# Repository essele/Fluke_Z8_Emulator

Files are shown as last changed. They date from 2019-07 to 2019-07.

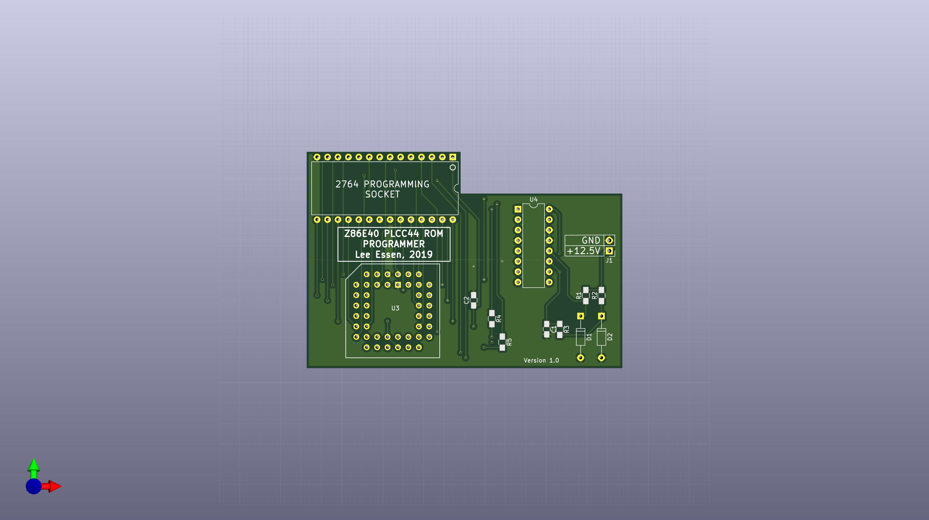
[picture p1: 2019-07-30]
pcb/8840A_CPU_Programmer/8840A_CPU_Programmer.jpg

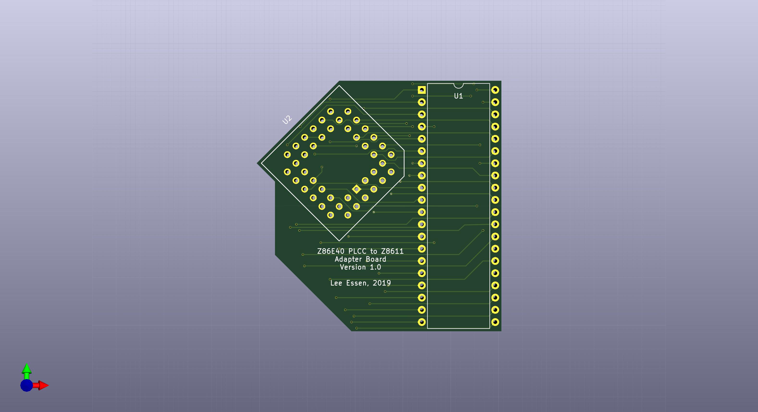
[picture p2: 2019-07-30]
pcb/8840A_CPU.jpg

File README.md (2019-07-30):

# Fluke_Z8_Emulator

This is a attempt at a Z8 emulator using a PSoC processor that can be used in a Fluke 8840A multimeter, and possibly a Fluke 8842A multimeter (although I have not tested the latter.)

I'm releasing this in the hope that someone will be able to help fix the remaining issue, the code is currently in a messy state as I've not had a chance to clean it up prior to releasing it.

The pcb and schematic (KiCad format) are available in the pcb directory.

The PSoC Creator workspace is in the PSoC_Workspace directory.

** THIS IS FAR FROM PRODUCTION WORTHY **

Some known issues:

1. There is a mistake on the PCB where all the P5 pins are offset by one, this doesn't cause a problem as it can be fixed by configuration, I'll fix this on the next version.

2. The GPIB board doesn't work properly. It works ok with external trigger set, but you get intermittent strange behaviour if not using the external trigger (more info below.)

3. I'm not entirely sure everything else is ok as I've hacked around with just about everything trying to fix the GPIB problem.

I'm fairly sure the outstanding issue is one of three things:

- A mis-implemented instruction
- Still something wrong with interrupts and masking
- A timing thing

Basic Description:

** I will spend some time documenting this properly, but for now here is a very brief overview **

Port 0 and 1 -- there is a verilog module that recreates the Z8 bus protocol which controls most of port 0 and 1.

Port 2 -- port 2 is a completely normal port, handled by firmware.

Port 3 -- port 3 is made up of incoming interrupts, one input sense line, and serial and timer.

Timer 1 -- the timer is implemented using a PSoC timer, but with a verilog module attached to the output to toggle the output at the end of each timing cycle. There is also the ability to set the output to 1 to copy the behaviour of the Z8 timer.

Serial -- currently there are three different serial implementations (all attempting to fix the GPIB problem), however the behaviour is the same with all of them, so I don't think it's related. The standard PSoC UART module is used for tx, I then have two verilog RX modules. SerialDRX is implemented using a datapath component so is lightweight and needs to be used if the timer block is also used. (I'm quite pleased with this as it's super efficient as it uses the datapath for both timer and shift register!)

TODO's for the next version...

1. Redo the whole bus access bit ... there are probably quite a lot of efficiencies to be had to give us more headroom for other things.

2. New board ... different output for the clock signal. Re-look at the P3 pins ... why did they stick the debug pins in the middle of a useful port???

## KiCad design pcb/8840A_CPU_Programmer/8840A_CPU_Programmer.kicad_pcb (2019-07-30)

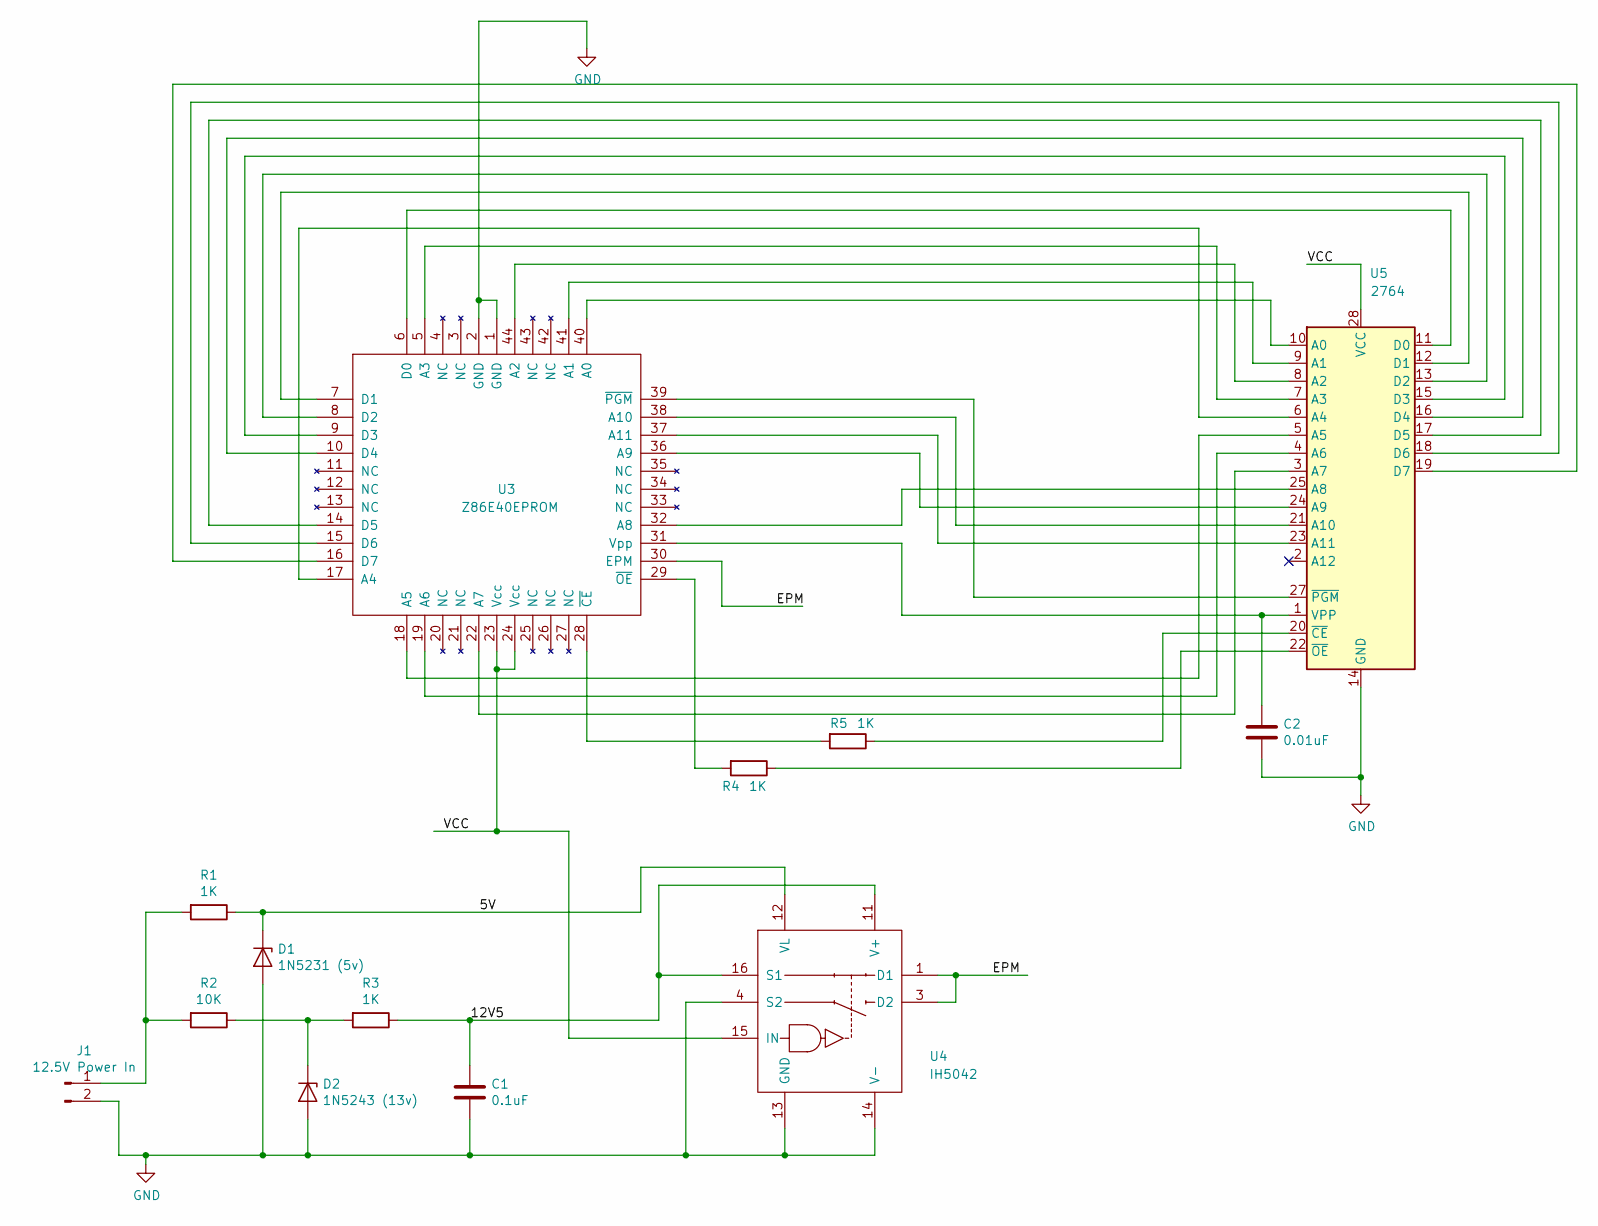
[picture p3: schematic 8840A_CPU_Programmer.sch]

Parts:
C1: 0.1uF; C_0805_HandSoldering
C2: 0.01uF; C_0805_HandSoldering
D1: 1N5231 (5v); D_DO-35_SOD27_P10.16mm_Horizontal
D2: 1N5243 (13v); D_DO-35_SOD27_P10.16mm_Horizontal
J1: 12.5V Power In; Pin_Header_Straight_1x02_Pitch2.54mm
R1, R3, R4, R5: 1K; R_0805_HandSoldering
R2: 10K; R_0805_HandSoldering
U3: Z86E40EPROM; PLCC44
U4: IH5042; DIP-16_W7.62mm
U5: 2764; DIP-28_W15.24mm

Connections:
/5V: D1.1 (K), R1.1, U4.12 (VL)
/12V5: C1.1, R3.1, U4.11 (V+), U4.16 (S1)
/EPM: U3.30 (EPM), U4.1 (D1), U4.3 (D2)
/VCC: U3.23 (Vcc), U3.24 (Vcc), U4.15 (IN), U5.28 (VCC)
GND: C1.2, C2.2, D1.2 (A), D2.2 (A), J1.2, U3.1 (GND), U3.2 (GND), U4.4 (S2), U4.13 (GND), U4.14 (V-), U5.14 (GND)
unnamed: C2.1, U3.31 (Vpp), U5.1 (VPP)
unnamed: D2.1 (K), R2.1, R3.2
unnamed: J1.1, R1.2, R2.2
unnamed: R4.1, U5.22 (~OE)
unnamed: R4.2, U3.29 (~OE)
unnamed: R5.1, U5.20 (~CE)
unnamed: R5.2, U3.28 (~CE)
unnamed: U3.5 (A3), U5.7 (A3)
unnamed: U3.6 (D0), U5.11 (D0)
unnamed: U3.7 (D1), U5.12 (D1)
unnamed: U3.8 (D2), U5.13 (D2)
unnamed: U3.9 (D3), U5.15 (D3)
unnamed: U3.10 (D4), U5.16 (D4)
unnamed: U3.14 (D5), U5.17 (D5)
unnamed: U3.15 (D6), U5.18 (D6)
unnamed: U3.16 (D7), U5.19 (D7)
unnamed: U3.17 (A4), U5.6 (A4)
unnamed: U3.18 (A5), U5.5 (A5)
unnamed: U3.19 (A6), U5.4 (A6)
unnamed: U3.22 (A7), U5.3 (A7)
unnamed: U3.32 (A8), U5.25 (A8)
unnamed: U3.36 (A9), U5.24 (A9)
unnamed: U3.37 (A11), U5.23 (A11)
unnamed: U3.38 (A10), U5.21 (A10)
unnamed: U3.39 (~PGM), U5.27 (~PGM)
unnamed: U3.40 (A0), U5.10 (A0)
unnamed: U3.41 (A1), U5.9 (A1)
unnamed: U3.44 (A2), U5.8 (A2)

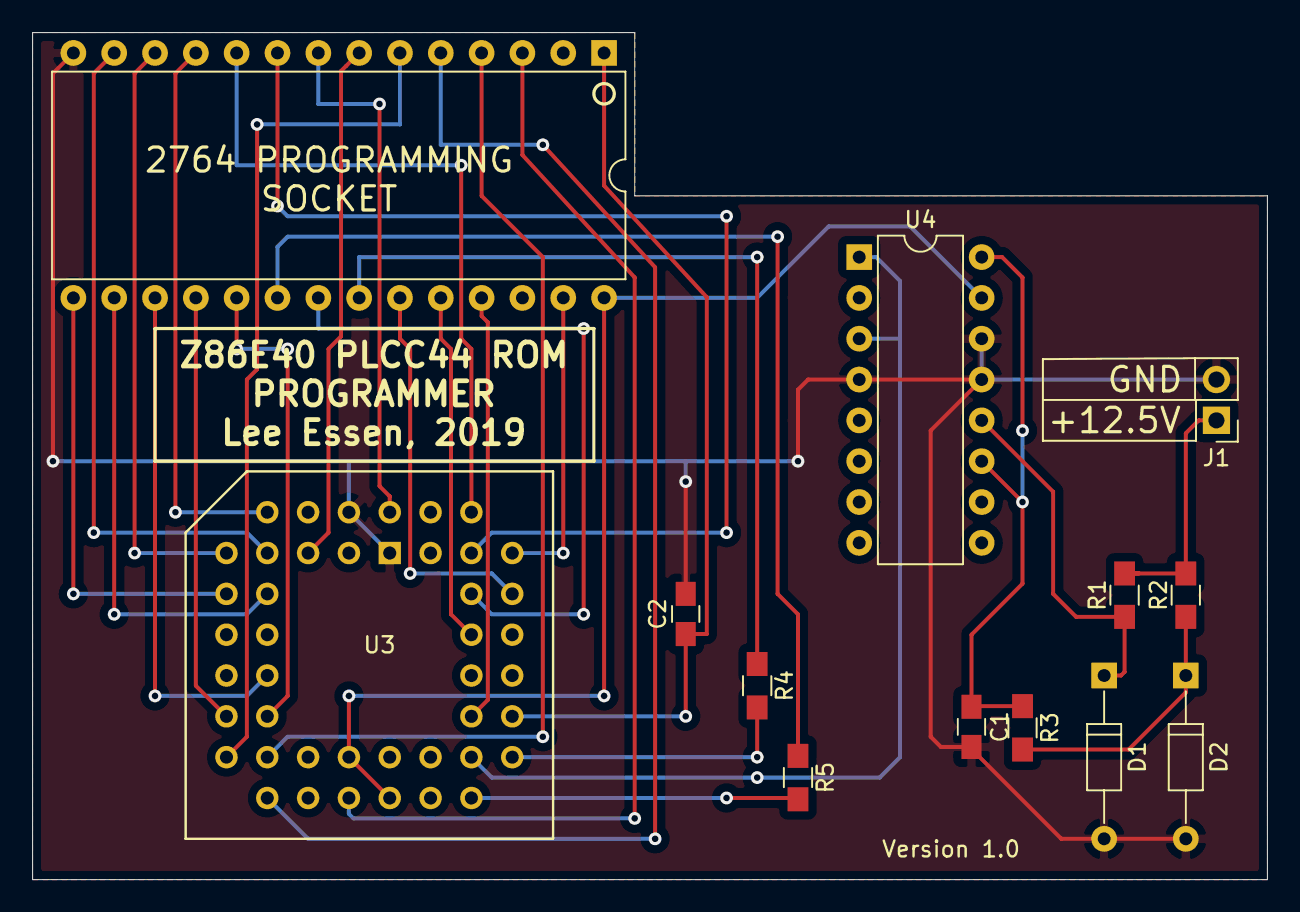
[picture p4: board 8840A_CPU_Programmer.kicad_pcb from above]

Board: 2 copper layers, 76.8 x 52.7 mm, 13 parts (0 on the bottom side), 33 nets.

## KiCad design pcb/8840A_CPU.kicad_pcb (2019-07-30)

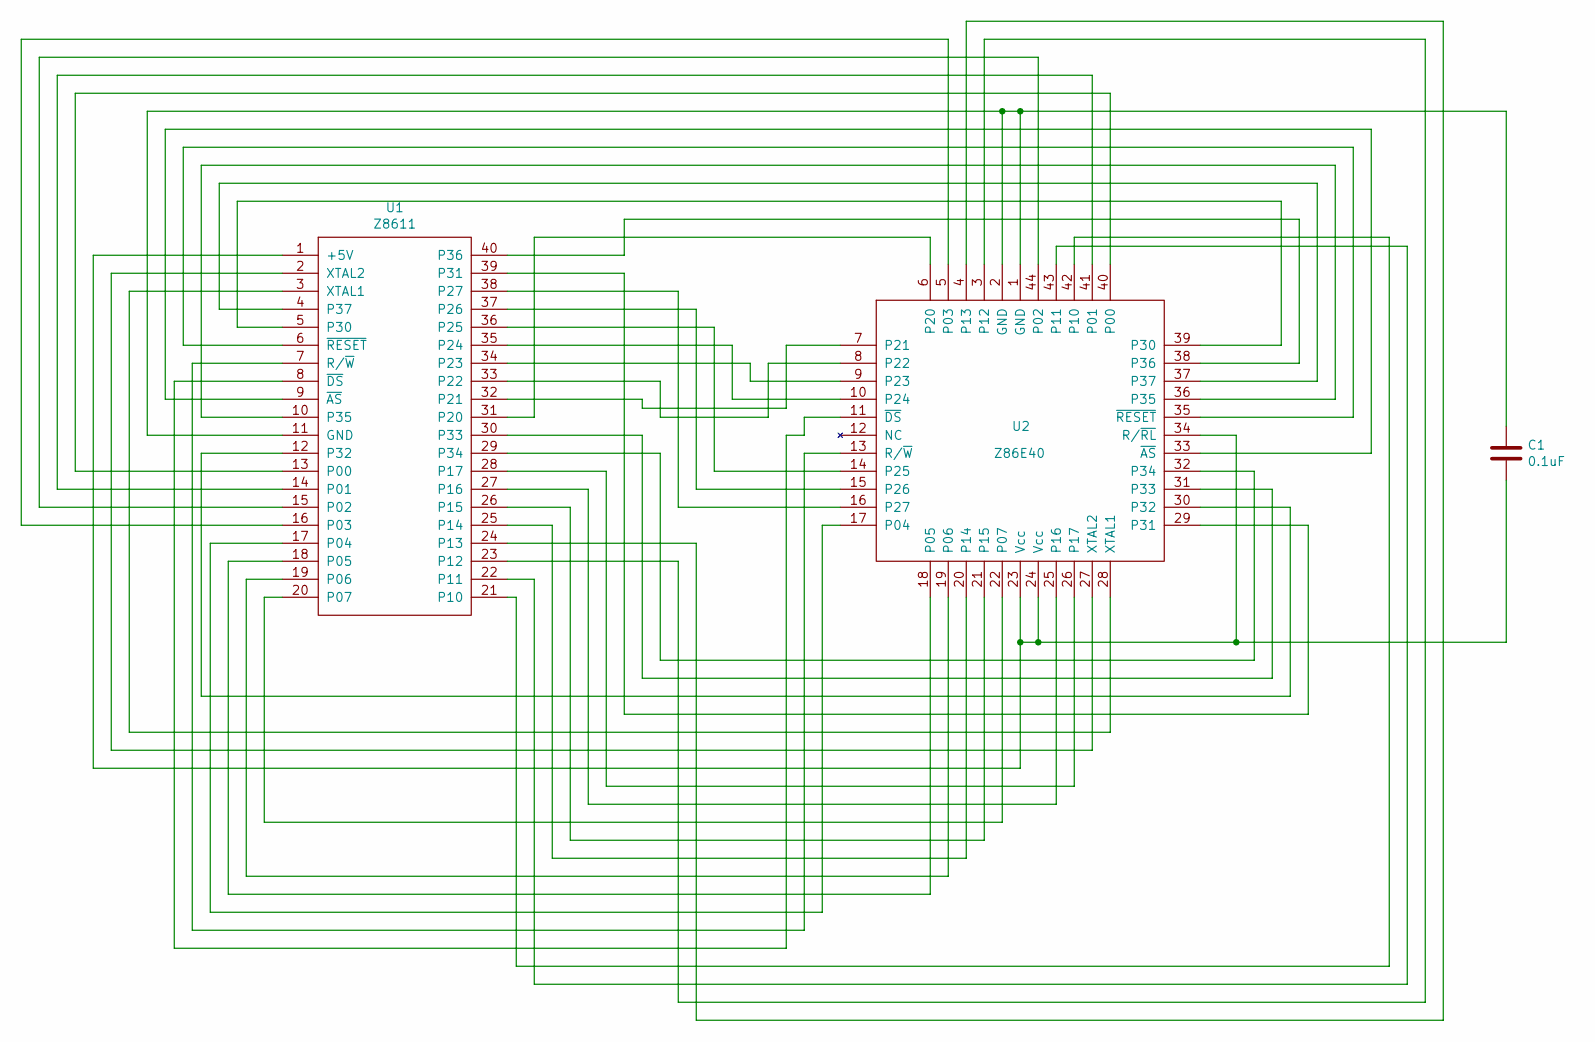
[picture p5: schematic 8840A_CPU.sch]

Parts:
C1: 0.1uF; C_0805_HandSoldering
U1: Z8611; DIP-40_W15.24mm
U2: Z86E40; PLCC44

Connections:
unnamed: C1.1, U1.11 (GND), U2.1 (GND), U2.2 (GND)
unnamed: C1.2, U1.1 (+5V), U2.23 (Vcc), U2.24 (Vcc), U2.34 (R/~RL)
unnamed: U1.2 (XTAL2), U2.27 (XTAL2)
unnamed: U1.3 (XTAL1), U2.28 (XTAL1)
unnamed: U1.4 (P37), U2.37
unnamed: U1.5 (P30), U2.39 (P30)
unnamed: U1.6 (~RESET), U2.35 (~RESET)
unnamed: U1.7 (R/~W), U2.13 (R/~W)
unnamed: U1.8 (~DS), U2.11 (~DS)
unnamed: U1.9 (~AS), U2.33 (~AS)
unnamed: U1.10 (P35), U2.36 (P35)
unnamed: U1.12 (P32), U2.30 (P32)
unnamed: U1.13 (P00), U2.40 (P00)
unnamed: U1.14 (P01), U2.41 (P01)
unnamed: U1.15 (P02), U2.44 (P02)
unnamed: U1.16 (P03), U2.5 (P03)
unnamed: U1.17 (P04), U2.17 (P04)
unnamed: U1.18 (P05), U2.18 (P05)
unnamed: U1.19 (P06), U2.19 (P06)
unnamed: U1.20 (P07), U2.22 (P07)
unnamed: U1.21 (P10), U2.42 (P10)
unnamed: U1.22 (P11), U2.43 (P11)
unnamed: U1.23 (P12), U2.3 (P12)
unnamed: U1.24 (P13), U2.4 (P13)
unnamed: U1.25 (P14), U2.20 (P14)
unnamed: U1.26 (P15), U2.21 (P15)
unnamed: U1.27 (P16), U2.25 (P16)
unnamed: U1.28 (P17), U2.26 (P17)
unnamed: U1.29 (P34), U2.32 (P34)
unnamed: U1.30 (P33), U2.31 (P33)
unnamed: U1.31 (P20), U2.6 (P20)
unnamed: U1.32 (P21), U2.7 (P21)
unnamed: U1.33 (P22), U2.8 (P22)
unnamed: U1.34 (P23), U2.9 (P23)
unnamed: U1.35 (P24), U2.10 (P24)
unnamed: U1.36 (P25), U2.14 (P25)
unnamed: U1.37 (P26), U2.15 (P26)
unnamed: U1.38 (P27), U2.16 (P27)
unnamed: U1.39 (P31), U2.29 (P31)
unnamed: U1.40 (P36), U2.38 (P36)

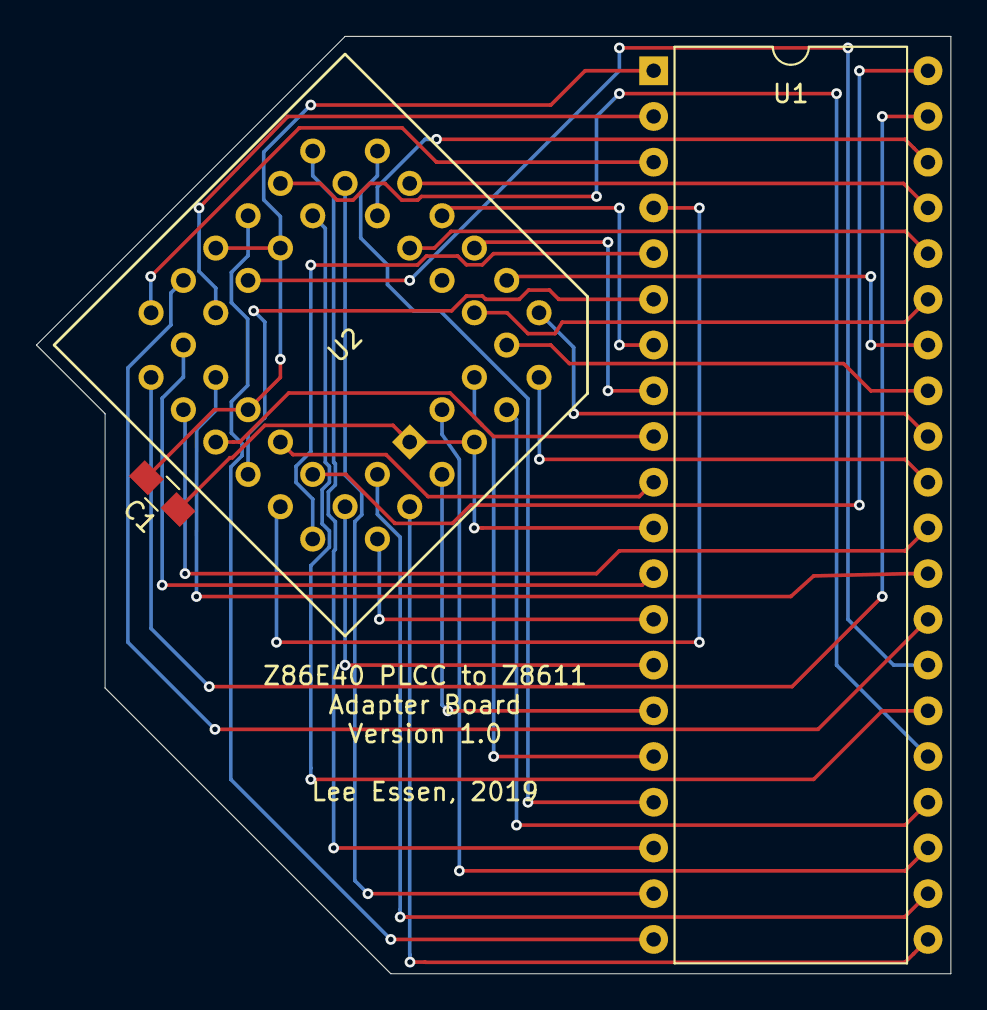
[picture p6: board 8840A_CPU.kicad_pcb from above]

Board: 2 copper layers, 50.8 x 52.1 mm, 3 parts (0 on the bottom side), 40 nets.

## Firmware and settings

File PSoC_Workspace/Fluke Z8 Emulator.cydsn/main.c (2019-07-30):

/* ========================================
 *
 * Copyright YOUR COMPANY, THE YEAR
 * All Rights Reserved
 * UNPUBLISHED, LICENSED SOFTWARE.
 *
 * CONFIDENTIAL AND PROPRIETARY INFORMATION
 * WHICH IS THE PROPERTY OF your company.
 *
 * ========================================
*/
#include "project.h"

#include "emulator.h"

uint8_t resp[64];

/**
    Read the external bus ...
        addr - 16 bit address
        dm - is is data memory (0=dm)
        ex - should we use extended timing (1=extend)

    TODO: move this code into the component API, but that will mean moving the
          control and status registers into there as well.
*/
uint8_t bus_read(uint16_t addr, int dm, int ex) {
    uint8_t hn;
    uint8_t rc;
    
//    if (addr == 0x1f00) {
        //if (ex != 1) BKPT;
//    }
        
    
    hn = (uint8_t)((addr & 0x0f00) >> 8);
    hn |= 0x80;                     // address
    if(ex) hn |= 0x10;              // extended bus timing
    if(dm) hn |= 0x20;              // dm

    // TODO: 16 bit reg write??
    
//    uint8_t saveInts = CyEnterCriticalSection();
    
//    (*(reg8 *)CYREG_UDB_W8_CTL0) = (uint8_t)(addr & 0xff);
//    CTRL1_Write((uint8_t)(addr&0xff));
//    (*(reg8 *)CYREG_UDB_W8_CTL1) = (uint8_t)hn;
//    CTRL2_Write(hn);
    
    uint16_t vvv = (hn << 8);
  
    vvv |= (addr & 0xff);

    IRQ_DVALID_ClearPending();
    (*(reg16 *)CYREG_UDB_W16_CTL0) = vvv;
//    CyDelayCycles(100);
//    (*(reg16 *)CYREG_UDB_W16_CTL1) = (uint16_t)(hn) | ((addr & 0xff) << 8);
    
    // We need a delay to ensure the data is ready to read, this seems
    // to be a minimum of 8 (we'll go 10) for the non-extended and an extra
    // 4 for extended. (Be careful with anything that changes the execution
    // time here. The time to do the math is important!)
//    CyDelayCycles(10 + (ex * 8));
//    CyDelayCycles(100);
    
    while(!(*IRQ_DVALID_INTC_SET_PD & (uint32)IRQ_DVALID__INTC_MASK));
    
    rc = DATA1_Read();
//    CyExitCriticalSection(saveInts); 
    return rc;
}

void bus_write(uint16_t addr, uint8_t data, int dm) {
    uint8_t hn;
    
    // First we write the data to the data register
    uint8_t saveInts = CyEnterCriticalSection();

    CTRL1_Write(data);
    CTRL2_Write(0x40);      // data strobe (loads data)
//   (*(reg16 *)CYREG_UDB_W16_CTL0) = (uint16_t)data | (0x40 << 8);
    
    hn = (uint8_t)((addr & 0x0f00) >> 8);
    hn |= 0x80;                     // address (bit 15 = 1)
    hn |= 0x00;                     // don't set extended timing (bit 12 = 0)
    if(dm) hn |= 0x20;              // dm (bit 13)
    
    CTRL1_Write((uint8_t)(addr&0xff));
    CTRL2_Write(hn);
//    (*(reg16 *)CYREG_UDB_W16_CTL0) = (uint16_t)(addr & 0xff) | (hn << 8);

    // Now we probably need to wait for some considerable time before this is
    // processed ... we should probably wait at least 30 cycles for now.
    // TODO: need to figure out how to optimise this
    // (Seems to work ok without any!)
//    CyDelayCycles(100);
    CyExitCriticalSection(saveInts); 
}

/**
 * MAIN entry point
 */
int main(void)
{
    // Start the external 8Mhz clock generator
    PWM8M_Start();
    
    // Setup timer1 (as per Z8 timer1)
    Timer1_Init();
    Timer1_Enable();
    Timer1_TriggerCommand(Timer1_MASK, Timer1_CMD_STOP);
    
    // Setup the UART with the default 8840A settings...
    UART_Start();
    
    // Prepare the CPU emulator and setup IRQ's...
    setup_emulator();
    
    //IRQ_SRX_Start();
    
  
    
    int c;
    uint8_t vals[16];

    /*
    
    for (c=0; c < 15; c++) {
        
        
        while ((*IRQ_SRX_INTC_SET_PD & (uint32)IRQ_SRX__INTC_MASK) == 0u);

        uint8_t vv = SR1_Read();
        vals[c] = vv;
        IRQ_SRX_ClearPending();
    }        
    
     */  
    
    
    // Run the emulator forever...
    execute();
}

/* [] END OF FILE */

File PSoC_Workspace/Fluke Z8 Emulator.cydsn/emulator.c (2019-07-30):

/* ========================================
 *
 * Copyright YOUR COMPANY, THE YEAR
 * All Rights Reserved
 * UNPUBLISHED, LICENSED SOFTWARE.
 *
 * CONFIDENTIAL AND PROPRIETARY INFORMATION
 * WHICH IS THE PROPERTY OF your company.
 *
 * ========================================
*/

#include "project.h"
#include <stdio.h>
#include <stdlib.h>
#include "emulator.h"



#undef USE_UART            


// Generic IRQ calling macro
#define     CALL_IRQ(n)     PUSH16(pc) \
                            PUSH(FLAGS) \
                            pc = code[(n*2)] << 8 | code[(n*2)+1]; \
                            IMR &= 0x7f;

//                            IRQ &= ~(1 << n); \
                            
                       
/**
 * Globals that represent the main state of the CPU
 */
uint16_t            pc;
uint8_t             reg[256];

// We use ints for the flags and keep them independently for speed, when accessing the
// flags register we'll have to pull them together
int                 C, Z, S, V, D, H;

// Do we need to use extended bus timing for read accesses to the external bus
int                 extended_bus_timing;

// Is the bus enabled or disabled (used for reading port 1)
int                 bus_enabled;


/**
 * FLAGS: We need to be able to combine the flags for a register read or write
 */
uint8_t read_FLAGS() {
    uint8_t f = FLAGS & 0x03;       // keep the two user flags

    if (C) f |= 0x80;
    if (Z) f |= 0x40;
    if (S) f |= 0x20;
    if (V) f |= 0x10;
    if (D) f |= 0x08;
    if (H) f |= 0x04;
    return f;
}
void write_FLAGS(uint8_t val) {
    FLAGS = val;

    C = ((val & 0x80) == 0x80);
    Z = ((val & 0x40) == 0x40);
    S = ((val & 0x20) == 0x20);
    V = ((val & 0x10) == 0x10);
    D = ((val & 0x08) == 0x08);
    H = ((val & 0x04) == 0x04);
}

/**
 * If we try to write a value to a register that we can't support then
 * we end up here, with some helpful local variables and a breakpoint to
 * the debugger.
 */
#pragma GCC push_options
#pragma GCC optimize ("O0")
void REG_FAIL(uint8_t __attribute__((unused)) reg, uint8_t __attribute__((unused)) val) {
    uint16_t    __attribute__((unused)) pc_after = pc;
    
    BKPT;
}
#pragma GCC pop_options


// ----------------------------------------------------------------------
// P01M -- controlling port 0 and port 1 (write only!)
// 
// Bit 7/6: P04-P07 mode (00=output, 01=input, 1X=A12-A15)    [1X NOT SUP]
// Bit 5:   External memory timing (0=normal, 1=extended)  
// Bit 4/3: P10-P17 mode (00=output, 01=input, 10=AD0-AD7, 11=HiZ all)
// Bit 2:   Stack (0=external, 1=internal)                    [INTERNAL only]
// Bit 1/0: P00-P03 mode (00=output, 01=input, 1X=A8-A11)
// 
// KNOWN VALUES for 8840A
//
// 06 -- A8-A11 addressing, internal stack, P04-P07 outputs, P1 byte output
// 16 -- A0-A11 addressing, internal stack, P04-P07 outputs, P1 Addr/Data
// 36 -- A0-A11 addressing, internal stack, P04-P07 outputs, P1 Addr/Data (EXTBUS)
// ----------------------------------------------------------------------
void write_P01M(uint8_t val) {
    
    
    switch(val) {
        case 0x06:      
                        *(uint32_t *)CYREG_HSIOM_PORT_SEL1 = 0x00000000;    // GPIO control
                        extended_bus_timing = 0;
                        bus_enabled  = 0;
            break;
        case 0x16:      
                        *(uint32_t *)CYREG_HSIOM_PORT_SEL1 = 0x22222222;    // DSI pin and OE
                        extended_bus_timing = 0;  /* 0 */
                        bus_enabled  = 1;
            break;
        case 0x36:
                        *(uint32_t *)CYREG_HSIOM_PORT_SEL1 = 0x22222222;    // DSI pin and OE
                        extended_bus_timing = 1;
                        bus_enabled  = 1;
            break;
        default:           
                        REG_FAIL(P01M, val);
    }
 
    // Always have P00 to P03 connected to DSI, and P04 to P07 as GPIO
    // Always have P00 to P03 as inputs (although not used for that) and P04 to P07 as outputs
    // This is done by the top level design, so don't actually need to do it here...
    /*
    *(uint32_t *)CYREG_HSIOM_PORT_SEL0 = 0x00003333;
    P0_PC = (
        (0x01 << 0) | (0x01 << 3) | (0x01 << 6) | (0x01 << 9) |         // P00 to P03 as input
        (0x06 << 12) | (0x06 << 15) | (0x06 << 18) | (0x06 << 21));     // P04 to P07 as output

    P1_PC = (
        (0x06 << 0) | (0x06 << 3) | (0x06 << 6) | (0x06 << 9) | 
        (0x06 << 12) | (0x06 << 15) | (0x06 << 18) | (0x06 << 21));     // all outputs
    */
}
// ----------------------------------------------------------------------
// P2M -- controlling port 2 (write only)
// 
// Simple mapping to bits to direction (0=output, 1=input)
//
// KNOWN VALUES for 8840A
//
// FB -- all input apart from P22 (test entry check)
// 0B -- P24-P27 output, P22 output, P20/21/23 input (normal)
// ----------------------------------------------------------------------
void write_P2M(uint8_t val) {
    // TODO: write to correct PSoC register
    
    switch(val) {
        case 0xfb:      // All inputs apart from P22
                        P2_PC = (
                            (0x01 << 0) | (0x01 << 3) | (0x06 << 6) |
                            (0x01 << 9) | (0x01 << 12) | (0x01 << 15) |
                            (0x01 << 18) | (0x01 << 21)); 
            break;
        case 0x0b:      // P20/21/23 input, P22 output, P24/25/26/27 output
                        P2_PC = (
                            (0x01 << 0) | (0x01 << 3) | (0x06 << 6) |
                            (0x01 << 9) | (0x06 << 12) | (0x06 << 15) |
                            (0x06 << 18) | (0x06 << 21)); 
            break;
        default:
                        REG_FAIL(P2M, val);
    }
    
}
// ----------------------------------------------------------------------
// P3M - controlling port 3 (write only)
//
// Bit 7:   Parity (0=off, 1=on)
// Bit 6:   P30 (0=input, 1=serialin)   P37 (0=output, 1=serialout)
// Bit 5:   P31 (0=input, 1=handshake)  P36 (0=output, 1=handshake)
// Bit 4/3: 00 (P33=in, P34=out) 01or10 (P33=in, P34=DM), 11 (P33=HS, P34=HS)
// Bit 2:   P32 (0=input, 1=handshake)  P35 (0=output, 1=handshake)
// Bit 1:   RESERVED
// Bit 0:   0=port2-pullups open drain, 1=port2-pullups active
//
// KNOWN VALUES for 8840A
//
// C9 - parity on, serial in/out, P31/P32/P33 input, P34 DM, P35/P36 output
//              port 2 pullups active
//
// PIN MAPPING (Z8 to PSoC)
//
// P30 -> P30 (serial out)
// P31 -> P40 (input)
// P32 -> P41 (input)
// P33 -> P42 (input)
// P34 -> P34 (DM)
// P35 -> P35 (reset for kbd controller)
// P36 -> P36 (T1 output, so ignore here)
// P37 -> P31 (serial in)
// ----------------------------------------------------------------------
void write_P3M(uint8_t val) {
    // We only support the value of C9, and that's how the design is setup, so
    // nothing really to do here.
    if (val != 0xC9) REG_FAIL(P3M, val);
}
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

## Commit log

2019-07-14 instruction fixes, irq fixes .. now working
    [emulator.c, main.c]
2019-07-14 reworked interrupts, more responsive
    [emulator.c]
2019-07-15 Create sample docs index.html
2019-07-19 rework again of IRQs to try to get serial working
    [Z8_instructions.c, emulator.c, main.c]
2019-07-22 rework again of the irq code
    [Z8_instructions.c, emulator.c, main.c]
2019-07-30 added pcb and schematic
    [8840A_CPU-B_Cu.gbr, 8840A_CPU-B_Mask.gbr, 8840A_CPU-B_Paste.gbr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]
2019-07-30 further cleanup, creation of timer component
